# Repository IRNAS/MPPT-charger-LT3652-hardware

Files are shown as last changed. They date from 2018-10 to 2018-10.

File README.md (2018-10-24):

irnas_logo
# MPPT-charger-LT3652-hardware
MPPT charger with LT3652 chip

MPPT charger board with LT3652 chip, is a stepdown battery charger that operates over a 4.95V to 32V input voltage range. It works perfectly for solar power based IOT applications. The LT3652 provides a constant-current/constant-voltage charge characteristic, with maximum charge current externally programmable up to 2A.  The charger employs a 3.3V float voltage feedback reference, so any desired battery float voltage up to 14.4V can be programmed with a resistor divider.

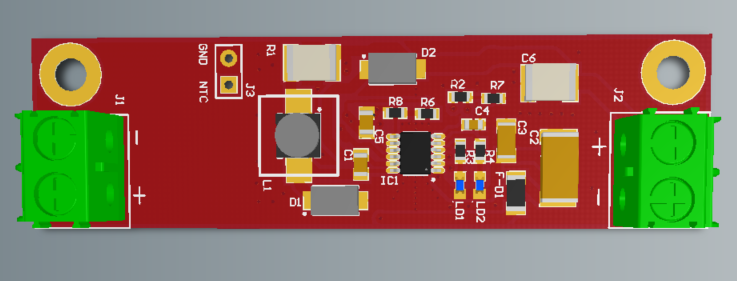
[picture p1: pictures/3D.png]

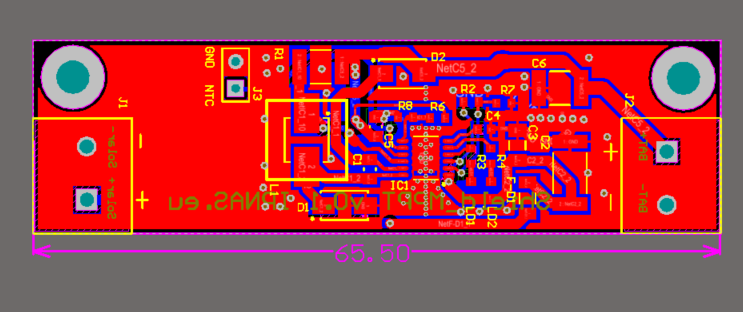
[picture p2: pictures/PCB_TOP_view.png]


#### License

All our projects are as usefully open-source as possible.

Hardware including documentation is licensed under [CERN OHL v.1.2. license](http://www.ohwr.org/licenses/cern-ohl/v1.2)

Firmware and software originating from the project is licensed under [GNU GENERAL PUBLIC LICENSE v3](http://www.gnu.org/licenses/gpl-3.0.en.html).

Open data generated by our projects is licensed under [CC0](https://creativecommons.org/publicdomain/zero/1.0/legalcode).

All our websites and additional documentation are licensed under [Creative Commons Attribution-ShareAlike 4 .0 Unported License](https://creativecommons.org/licenses/by-sa/4.0/legalcode).

What this means is that you can use hardware, firmware, software and documentation without paying a royalty and knowing that you'll be able to use your version forever. You are also free to make changes but if you share these changes then you have to do so on the same conditions that you enjoy.

Koruza, GoodEnoughCNC and IRNAS are all names and marks of Institut IRNAS Rače. 
You may use these names and terms only to attribute the appropriate entity as required by the Open Licences referred to above. You may not use them in any other way and in particular you may not use them to imply endorsement or authorization of any hardware that you design, make or sell.

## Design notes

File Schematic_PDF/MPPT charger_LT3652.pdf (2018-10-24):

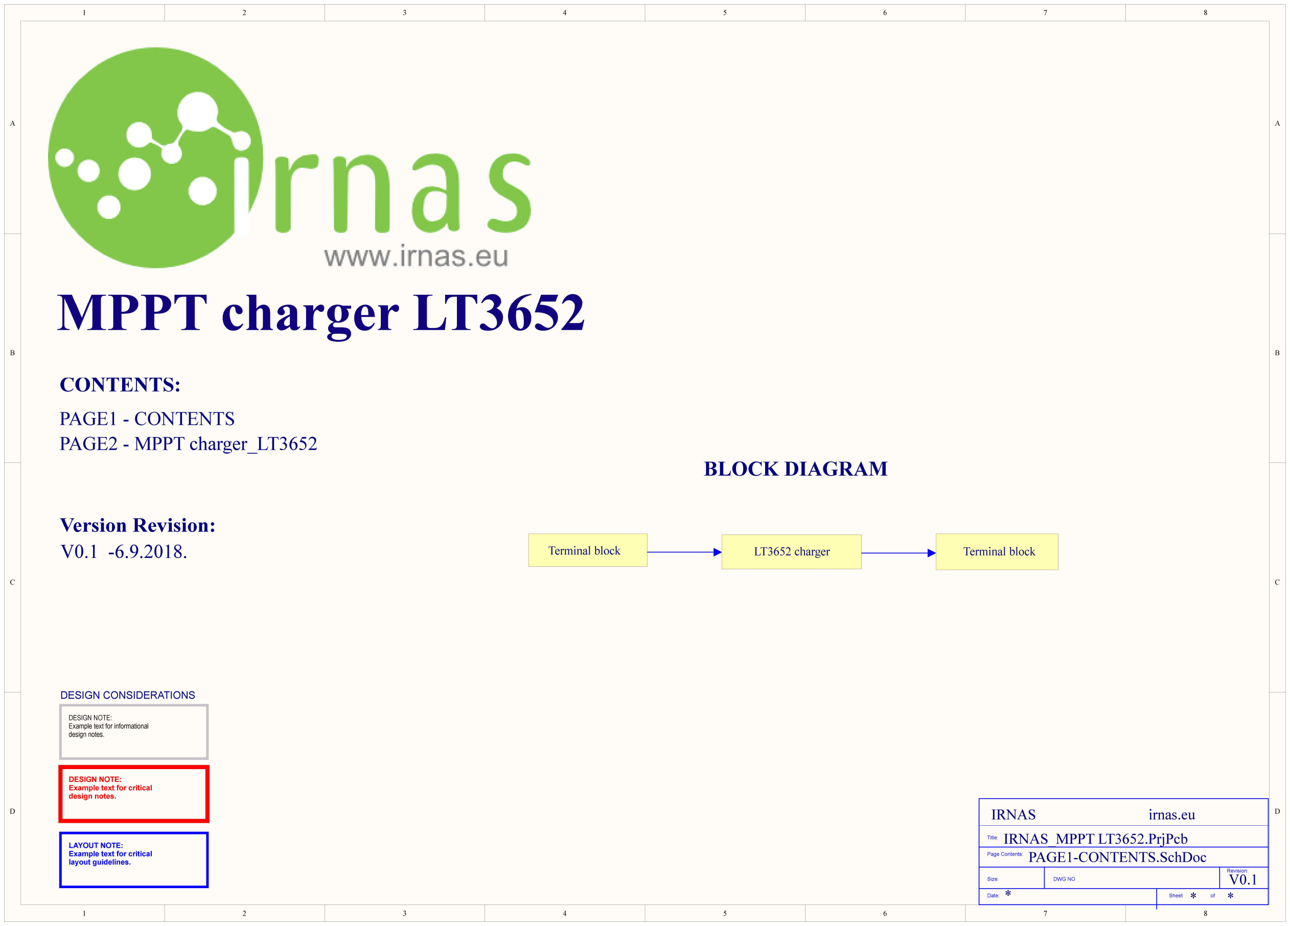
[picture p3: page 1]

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
# CONTENTS:

# PAGE1 - CONTENTS PAGE2 - MPPT charger_LT3652

# Version Revision:

# MPPT charger LT3652

## DESIGN CONSIDERATIONS

DESIGN NOTE:
Example text for informational
design notes.

DESIGN NOTE:
Example text for critical
design notes.

LAYOUT NOTE:
Example text for critical
layout guidelines.

V0.1 -6.9.2018.

Size:

Date:

DWG NO

Revision:

Sheet | of

Title:

Page Contents:

IRNAS | irnas.eu

# IRNAS_MPPT LT3652.PrjPcb

| PAGE1-CONTENTS.SchDoc
* | * | * V0.1
Terminal block | LT3652 charger | Terminal block

# BLOCK DIAGRAM

2A C2

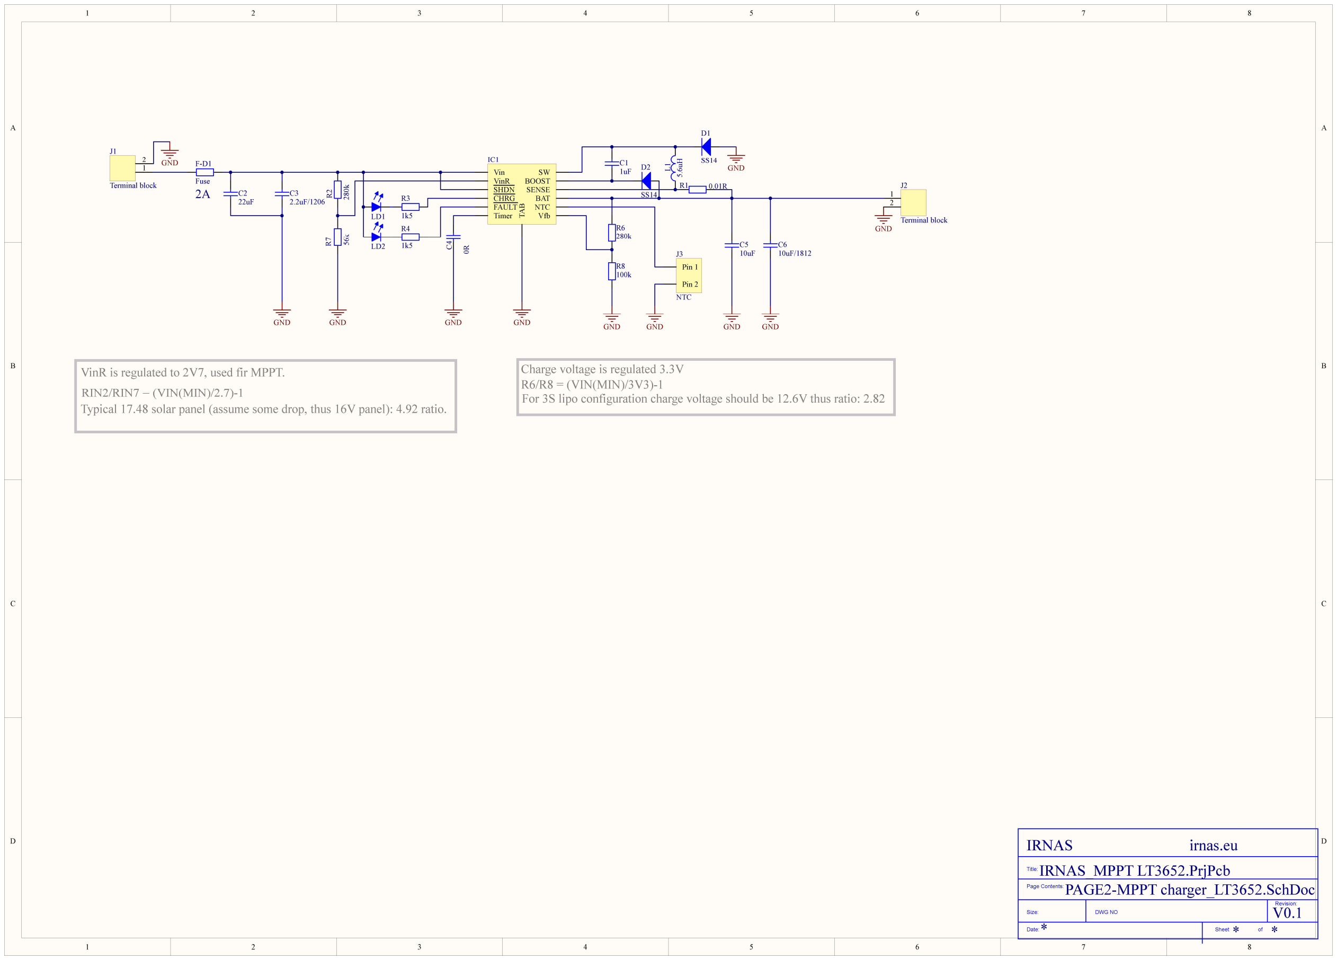
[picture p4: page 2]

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
A A 0RC⁴

Vin
VinR
SHDN
CHRG
FAULT

Timer Vfb NTC BAT

SENSE

BOOST

SW TAB

IC1

Pin 1

Pin 2

J3

NTC

GND | GND | GND | GND | GND | GND

GND

GND

GND

GND

1

2

J1

Terminal block

GND

1
2

J2
Terminal block R² | 280k R⁷ | 56k

1k5

R3

1k5

R4 | R6 280k
| R8 100k

D1

SS14
D2

SS14 L¹ 5.6uH

R1 0.01R

LD1

LD2

F-D1

Fuse

22uF

C3
2.2uF/1206

C1
1uF

C5
10uF

C6
10uF/1812

Size:

Date:

DWG NO

Revision:

Sheet | of

Title:

Page Contents:

IRNAS | irnas.eu

# IRNAS_MPPT LT3652.PrjPcb PAGE2-MPPT charger_LT3652.SchDoc

* | * | * V0.1

VinR is regulated to 2V7, used fir MPPT.

## RIN2/RIN7 = (VIN(MIN)/2.7)-1

Typical 17.48 solar panel (assume some drop, thus 16V panel): 4.92 ratio.

## Charge voltage is regulated 3.3V R6/R8 = (VIN(MIN)/3V3)-1 For 3S lipo configuration charge voltage should be 12.6V thus ratio: 2.82

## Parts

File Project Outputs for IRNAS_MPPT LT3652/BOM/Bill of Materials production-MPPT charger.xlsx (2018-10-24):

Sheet: Part List Report
 | Component list |  |  | <Parameter ProjectTitle not found>
 | Source Data From: | MPPT charger.PcbDoc |  |  | Contact:
 | Project: | IRNAS_MPPT LT3652.PrjPcb
 | Variant: | None |  |  |  |  |  |  | IRNAS
 | Report Date: | 09/11/2018 | 5:05:48 PM |  |  |  |  |  | www.irnas.eu
 | Print Date: | 2018-09-11 | 17:19:05
# | Manufacturer Part Number 1 | Manufacturer 1 | Description | Footprint | Designator | Quantity | Supplier 1 | Supplier Part Number 1 | Supplier Order Qty 1 | Supplier Stock 1 | Supplier Unit Price 1 | Supplier Subtotal 1 | Supplier Currency 1
1 | TMCMA1V225MTRF (https://octopart-clicks.com/click/altium?sku=2491481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) | Vishay Sprague (https://octopart-clicks.com/click/altium?sku=2491481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) |  | 1206 CAP | C3 | 1 | Farnell | 2773322 (https://octopart-clicks.com/click/altium?sku=2491481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) | 50 | 0 | 0.59 | 29.39 | EUR
2 | CRCW060339K0FKEA (https://octopart-clicks.com/click/altium?sku=1469804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) | Vishay (https://octopart-clicks.com/click/altium?sku=1469804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) |  | 0603 RES | R7 | 1 | Farnell | 9238670 (https://octopart-clicks.com/click/altium?sku=1469804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) | 40 | 0 | 0.02 | 0.66 | EUR
3 | WSLT2010R0100FEA18 (https://octopart-clicks.com/click/altium?sku=2420772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) | Vishay (https://octopart-clicks.com/click/altium?sku=2420772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) |  | 1812 RES | R1 | 1 | Farnell | 2420772 (https://octopart-clicks.com/click/altium?sku=2420772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) | 40 | 12742 | 1.17 | 46.80 | EUR
4 | CRCW08051K50FKEA (https://octopart-clicks.com/click/altium?sku=1652940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) | Vishay (https://octopart-clicks.com/click/altium?sku=1652940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) | 1K5 | 0603 RES | R3, R4 | 2 | Farnell | 1652940 (https://octopart-clicks.com/click/altium?sku=1652940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) | 100 | 23878 | 0.02 | 2.30 | EUR
5 | 1715022 (https://octopart-clicks.com/click/altium?sku=3714240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) | Phoenix Contact (https://octopart-clicks.com/click/altium?sku=3714240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) | CONN TERM BLOCK 2POS 5MM PCB | TERMINAL BLOCK - 2 WAYS | J1, J2 | 2 | Farnell | 3714240 (https://octopart-clicks.com/click/altium?sku=3714240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) | 80 | 2647 | 0.99 | 79.52 | EUR
6 | ERA-3AEB104V (https://octopart-clicks.com/click/altium?sku=1577632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) | Panasonic (https://octopart-clicks.com/click/altium?sku=1577632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) |  | 0603 RES | R6 | 1 | Farnell | 1577632 (https://octopart-clicks.com/click/altium?sku=1577632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) | 40 | 24842 | 0.19 | 7.60 | EUR
7 | ERA-3AEB304V (https://octopart-clicks.com/click/altium?sku=1670209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) | Panasonic (https://octopart-clicks.com/click/altium?sku=1670209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) |  | 0603 RES | R8 | 1 | Farnell | 1670209 (https://octopart-clicks.com/click/altium?sku=1670209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) | 40 | 12709 | 0.21 | 8.36 | EUR
8 | ERA-3AEB473V (https://octopart-clicks.com/click/altium?sku=1577628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) | Panasonic (https://octopart-clicks.com/click/altium?sku=1577628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) | RESISTOR, 0603, 47K, FULL REEL | 0603 RES | R2 | 1 | Farnell | 1577628 (https://octopart-clicks.com/click/altium?sku=1577628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) | 40 | 28267 | 0.19 | 7.51 | EUR
9 | SS14FL (https://octopart-clicks.com/click/altium?sku=2822564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) | ON Semiconductor / Fairchild (https://octopart-clicks.com/click/altium?sku=2822564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) | High Conductance Fast Diode | SMB | D1, D2 | 2 | Farnell | 2822564 (https://octopart-clicks.com/click/altium?sku=2822564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) | 100 | 800 | 0.09 | 8.95 | EUR
10 | GRM219R61A106KE44D (https://octopart-clicks.com/click/altium?sku=1845741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) | Murata (https://octopart-clicks.com/click/altium?sku=1845741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) |  | 0805 CAP | C5 | 1 | Farnell | 1845741 (https://octopart-clicks.com/click/altium?sku=1845741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) | 40 | 2218 | 0.25 | 10.08 | EUR
11 | GCM21BR7YA105KA55L (https://octopart-clicks.com/click/altium?sku=2494199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) | Murata (https://octopart-clicks.com/click/altium?sku=2494199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) |  | 0805 CAP | C1 | 1 | Farnell | 2494199 (https://octopart-clicks.com/click/altium?sku=2494199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) | 50 | 666 | 0.21 | 10.50 | EUR
12 | FDSD0420-H-1R5M=P3 (https://octopart-clicks.com/click/altium?sku=2530091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) | Murata (https://octopart-clicks.com/click/altium?sku=2530091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) | Single coil | FDSD0420-H | L1 | 1 | Farnell | 2530091 (https://octopart-clicks.com/click/altium?sku=2530091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) | 50 | 1930 | 0.49 | 24.40 | EUR
13 | 703-0112 (https://octopart-clicks.com/click/altium?sku=2112124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) | Multicomp (https://octopart-clicks.com/click/altium?sku=2112124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) | LED | LED_0603 | LD1, LD2 | 2 | Farnell | 2112124 (https://octopart-clicks.com/click/altium?sku=2112124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) | 100 | 562 | 0.11 | 10.80 | EUR
14 | 0466002.NR (https://octopart-clicks.com/click/altium?sku=9921877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) | Littelfuse (https://octopart-clicks.com/click/altium?sku=9921877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) |  | 1206 RES | F-D1 | 1 | Farnell | 9921877 (https://octopart-clicks.com/click/altium?sku=9921877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) | 40 | 7633 | 0.56 | 22.44 | EUR
15 | C1812C106K3RACTU (https://octopart-clicks.com/click/altium?sku=1358500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) | KEMET (https://octopart-clicks.com/click/altium?sku=1358500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) |  | 1812 CAP | C6 | 1 | Farnell | 1358500 (https://octopart-clicks.com/click/altium?sku=1358500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) | 50 | 2483 | 2.36 | 118.00 | EUR
16 | T491D226K035AT (https://octopart-clicks.com/click/altium?sku=1457504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) | KEMET (https://octopart-clicks.com/click/altium?sku=1457504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) |  | 2512 CAP | C2 | 1 | Farnell | 1457504 (https://octopart-clicks.com/click/altium?sku=1457504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) | 50 | 11246 | 0.85 | 42.65 | EUR
17 |  |  |  | MSOP12 - EP | IC1 | 1 | Digi-Key | LT3652EMSE#PBF-ND | 40
 |  |  |  |  |  | 21 |  |  | 950 |  |  | 429.96
Approved |  |  |  | Notes
 |  |  |  | pcs: |  | 40 |  | Total |  | 429.96 |  | EUR
 |  |  |  |  |  |  |  | Price for 1pcs |  | 10.75 |  | EUR

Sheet: Project Information
Project Full Path | C:\Users\vojislav\OneDrive\IRNAS-Common\Electronics-Development\Agrelaeco\IRNAS_MPPT_charger\IRNAS_MPPT LT3652.PrjPcb
Project Filename | IRNAS_MPPT LT3652.PrjPcb
Variant Name | None
Data-Source Filename | MPPT charger.PcbDoc
Data-Source Full Path | C:\Users\vojislav\OneDrive\IRNAS-Common\Electronics-Development\Agrelaeco\IRNAS_MPPT_charger\MPPT charger.PcbDoc
Title | Bill of Materials production For PCB Document [MPPT charger.PcbDoc]
Total Quantity | 23
Report Time | 5:05:48 PM
Report Date | 09/11/2018
Report Date & Tine | 09/11/2018 5:05:48 PM
Output Name | Bill of Materials production
Output Type | BOM_PartType
Output Generator Name | BOM
Output Generator Description | Bill of Materials

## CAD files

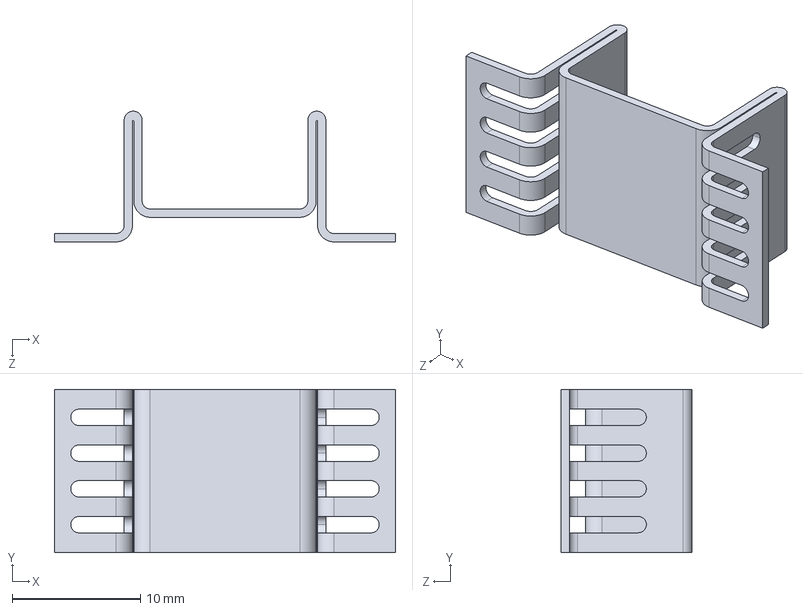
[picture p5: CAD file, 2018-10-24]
step_files/heatsink 3D/User Library-Prototype - AAVID 5733 Heatsink.step
26.5 x 12.7 x 10.2 mm

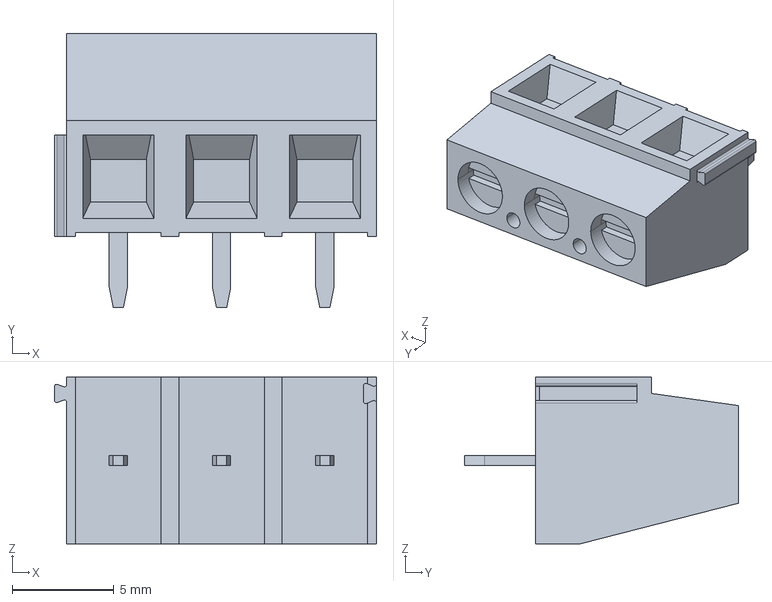
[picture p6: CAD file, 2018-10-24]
step_files/3D terminal 3way/2506361_282837-3.stp
15.8 x 13.5 x 8.20 mm

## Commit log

2018-10-24 MPPT charger LT3652 altium files
    [2506361_282837-3.stp, Bill of Materials production-MPPT charger.xlsx, IRNAS_MPPT LT3652.PrjPcb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]
2018-10-24 PCB pictures
